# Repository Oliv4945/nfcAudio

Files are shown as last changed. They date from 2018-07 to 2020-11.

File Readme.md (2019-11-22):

# Project
nfcAudio is a wifi enabled MP3 player with NFC capability. A tag is placed on top and corresponding file is played.

# Software
Each time an RFID tag is detected:  
1. It is compared to volume tags
2. If a music is playing with the same tag, stop playing
3. Else GET an URL from embedded NDEF record
4. If there the file contains an URL to an MP3 file, play it.

## Libraries
This project depends on
* [ESP8266 Audio](https://github.com/earlephilhower/ESP8266Audio) - Wonderfull MP3 decoder
* [Adafruit PN532](https://github.com/Oliv4945/Adafruit-PN532/tree/interrupt_spi) - NFC library from Adafruit, which I modified to use interrupts instead of defalut blocking functions. `interrupt_spi` branch from my repo has to be used until my pull request is merged. (configured by default in `platformio.ini` file)

# Hardware
## Tags
Small stickers as well as standard "credit card" size tags can be used. I use a printed picture with thermal laminated film, but you can buy tags that can be printed if you have corresponding printer.  
Stickers can also be put underneath objects, toys, 3D printed things... Lot of fun for my 3 years old kid !

## Components
* I2S DAC MAX98357A - From [Adafruit](https://www.adafruit.com/product/3006)
* ESP8266 - [Wemos mini D1](https://wiki.wemos.cc/products:d1:d1_mini)
* NFC Reader PN532

## Wiring
### I2S DAC - MAX98357A
| I2S DAC board  | Wemos mini D1 mini pin  | ESP8266 pin  |
| --- |:---:| ----:|
| LRC | D4  | IO2  |
| BLCK | D8  | IO15 |
| DIN | RX  | IO3  |
| GND | GND | GND  |
| VCC | 5V  | |

### NFC Reader - PN532
| NFC Reader  | Wemos mini D1 mini pin  | ESP8266 pin  |
| --- |:---:| ----:|
| SCK | D5  | IO14 |
| MISO | D6  | IO12 |
| MOSI | D7  | IO13 |
| SS | D1  | IO5  |
| VCC | 3.3V| |
| GND | GND | GND  |
| IRQ | D2  | IO4  |
| RST | NC  | NC |

## Case
Design files are available in [onShape](https://cad.onshape.com/documents/462111829eacaa66e3425406/w/186305e0bc17a139465da4be/e/d87f807332cb58a96165f9d4), or in the [case](https://github.com/Oliv4945/nfcAudio/case) folder.  
The onShape model is fully parametrized, so all variables can be changed to fit you needs.

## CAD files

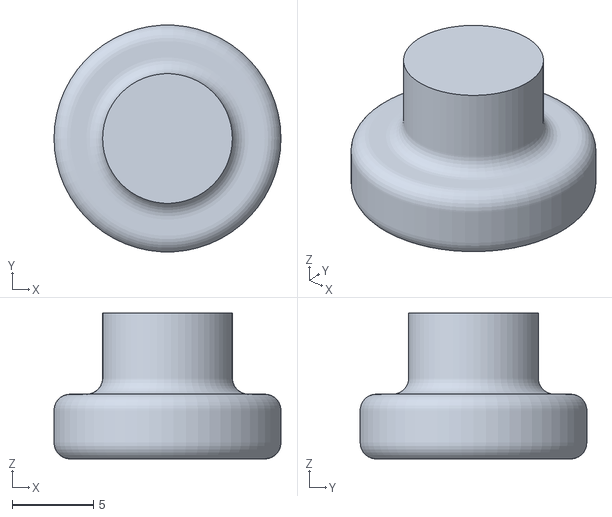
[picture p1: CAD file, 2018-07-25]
case/Foot.stl
14.0 x 14.0 x 9.00

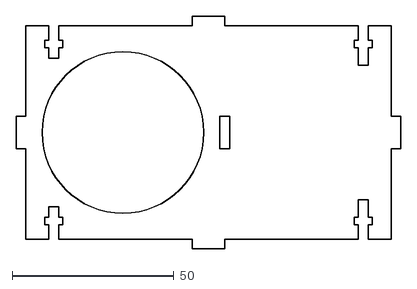
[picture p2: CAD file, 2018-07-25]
case/Bottom.dxf
119.0 x 72.0

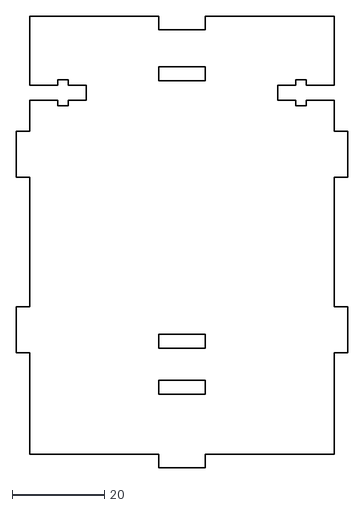
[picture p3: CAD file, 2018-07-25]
case/SideMiddle.dxf
72.0 x 98.0

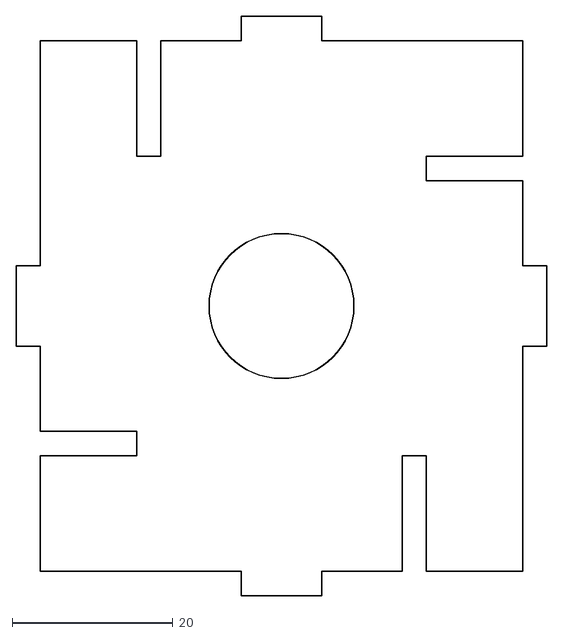
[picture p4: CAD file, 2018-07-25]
case/hpHolder.dxf
66.0 x 72.0

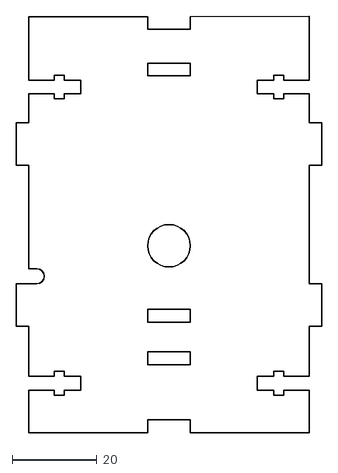
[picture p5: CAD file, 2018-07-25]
case/SideLeft.dxf
72.0 x 98.0

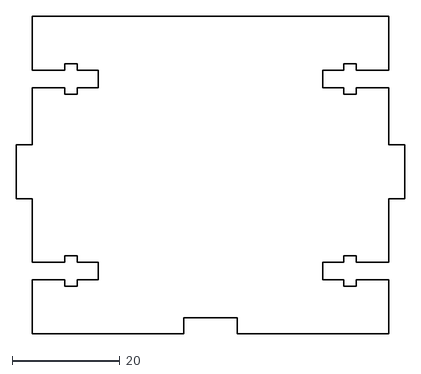
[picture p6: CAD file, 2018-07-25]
case/SideRight.dxf
72.0 x 58.8

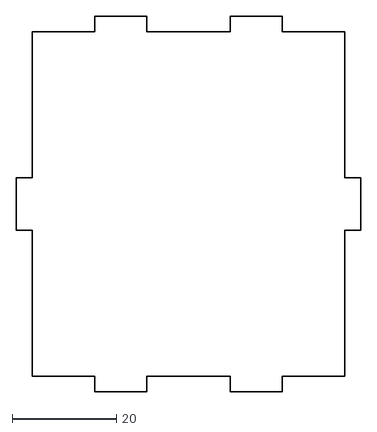
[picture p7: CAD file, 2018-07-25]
case/Top.dxf
66.0 x 72.0

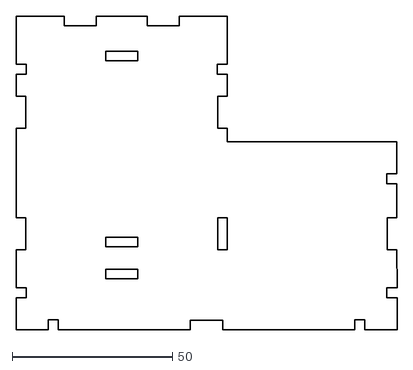
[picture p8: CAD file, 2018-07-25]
case/FrontBack_x2.dxf
119.0 x 98.0

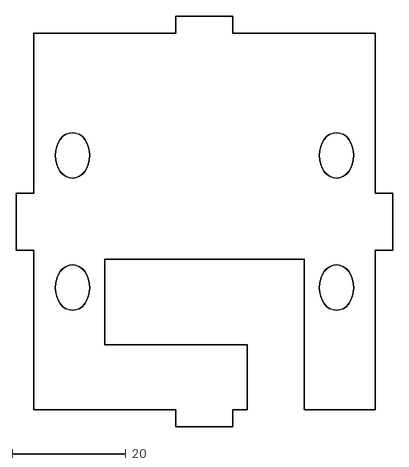
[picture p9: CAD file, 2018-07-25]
case/nfcHolder.dxf
66.0 x 72.0

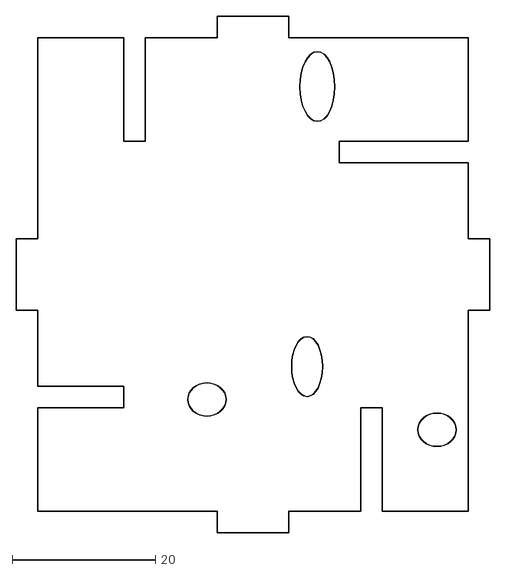
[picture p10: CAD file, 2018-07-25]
case/WemosAdcHolder.dxf
66.0 x 72.0

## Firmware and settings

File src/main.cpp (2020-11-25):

#include <Arduino.h>
#include <ESP8266WiFi.h>

#include <Wire.h>
#include <SPI.h>
#include "Adafruit_PN532.h"

#include "nfcPlayer.hpp"

#include "secrets.h"

// If using the breakout with SPI, define the pins for SPI communication.
#define PN532_SCK  (14)
#define PN532_MISO (12)
#define PN532_MOSI (13)
#define PN532_SS   (5)

// If using the breakout or shield with I2C, define just the pins connected
// to the IRQ and reset lines.  Use the values below (2, 3) for the shield!
#define PN532_IRQ   (4)
#define PN532_RESET (3)  // Not connected by default on the NFC Shield

// Hardware SPI
Adafruit_PN532 nfc(PN532_SS);


uint8_t uid[] = { 0, 0, 0, 0, 0, 0, 0 };  // Buffer to store the returned UID
uint8_t uidPlaying[]    = { 0, 0, 0, 0, 0, 0, 0 };  // Buffer to store the playing UID
uint8_t uidLength;                        // Length of the UID (4 or 7 bytes depending on ISO14443A card type)
uint8_t success = 0;
uint32_t timeoutNfc = 0;
bool interruptTriggered = false;
bool readerDisabled = false;


// Objects
nfcPlayer player;


// NFC interrupt handler
void ICACHE_RAM_ATTR handleInterrupt() {
  detachInterrupt(PN532_IRQ);
  interruptTriggered = true;
  readerDisabled = true;
}


void setup() {
  Serial.begin(115200);
  
  Serial.println("Connecting to WiFi");
  WiFi.begin(ssid, password);
  while (WiFi.status() != WL_CONNECTED) {
    delay(500);
    Serial.print(".");
  }
  Serial.println("\nIP address: ");
  Serial.println(WiFi.localIP());

  // NFC
  nfc.begin();
  uint32_t versiondata = nfc.getFirmwareVersion();
  if (! versiondata) {
    Serial.print("Didn't find PN53x board");
    while (1); // halt
  }
  // Got ok data, print it out!
  Serial.print("Found chip PN5"); Serial.println((versiondata>>24) & 0xFF, HEX); 
  Serial.print("Firmware ver. "); Serial.print((versiondata>>16) & 0xFF, DEC); 
  Serial.print('.'); Serial.println((versiondata>>8) & 0xFF, DEC);
  // configure board to read RFID tags
  nfc.SAMConfig();
  Serial.println("Waiting for an ISO14443A Card ...");

  // Register IRQ
  pinMode(PN532_IRQ, INPUT_PULLUP);
  nfc.startPassiveTargetIDDetection(PN532_MIFARE_ISO14443A);
  delay(500);
  attachInterrupt(digitalPinToInterrupt(PN532_IRQ), handleInterrupt, FALLING);
}


void processUid(uint8_t* uid, uint8_t uidLength) {
  String mp3Url;

  Serial.println("processUid");
  // Process volume
  if (memcmp(uid, uidVolumeDown, uidVolumeLen) == 0) {
    player.volumeDown();
    return;
  }
  if (memcmp(uid, uidVolumeUp, uidVolumeLen) == 0) {
    player.volumeUp();
    return;
  }
  // Stop playing in all cases
  if (player.isRunning()) player.stop();

  // Stop card
  if (memcmp(uid, uidStop, uidVolumeLen) == 0) {
    return;
  }

  // Try to read NTAG2xx memory and extract an URL
  // TODO: mifare classic/ultralight
  // TODO: Parsing from the app "NFC Reader" on Android Play store, not only the spec. To be validated
  // Read only the first record
  
  if (uidLength == 7) {

    uint8_t headerPage[4];
    // Read tag type, if any
    nfc.ntag2xx_ReadPage(4, headerPage);
    Serial.print("Header 4: ");
    nfc.PrintHex(headerPage, 4);
    Serial.println();
    if (headerPage[1] == 0x03) {
      Serial.println("NDEF RECORD");
      // Read header
      nfc.ntag2xx_ReadPage(5, headerPage);
      Serial.print("Header 5: ");
      nfc.PrintHex(headerPage, 4);
      Serial.println();
      if ((headerPage[3] && 0x07) == 0x01) {
        nfc.ntag2xx_ReadPage(6, headerPage);
        Serial.print("Header 6: ");
        nfc.PrintHex(headerPage, 4);
        Serial.println();
        Serial.println("NDEF - Well know record");
        if (headerPage[2] == 0x55) {
          Serial.println("NDEF - Well know URI");
          switch(headerPage[3]) {
            case 0x01:
              mp3Url = "http://www.";
              break;
            case 0x02:
              mp3Url = "https://www.";
              break;
            case 0x03:
              mp3Url = "http://";
              break;
            case 0x04:
              mp3Url = "https://";
              break;
            default:
              Serial.print("NDEF - Value: '0x");
              Serial.print(headerPage[3], HEX);
              Serial.println("' unknown.");
          }
          // Read URL
          uint8_t data[((headerPage[1]-1)/4+1)*4+1];
          for (uint8_t page = 7; page < ((headerPage[1]-1)/4+1) + 7; page ++) {
            nfc.ntag2xx_ReadPage(page, data + (page - 7) * 4);
          }
          data[headerPage[1]-1] = '\0';
          nfc.PrintHex(data, 12);
          mp3Url += String((char *) data);
          Serial.print("NDEF - URL: ");
          Serial.println(mp3Url);
        }
      }
    }
  }

  if (mp3Url.length() == 0) {
    // Try to connect to the server in order to get an URL to play
    WiFiClient client;
    if (!client.connect(host, port)) {
      Serial.println("connection failed");
      return;
    }
    String url = String("/nfcAudio/uid/0x");
    for (uint8_t i = 0; i< uidLength; i++) {
      url += String(uid[i], HEX);
    }
    Serial.print("URL: ");
    Serial.println(url);
    // Send request
    client.print(String("GET ") + url + " HTTP/1.1\r\n" +
                "Host: " + host + "\r\n" +
                "Connection: close\r\n\r\n"
      );
    unsigned long timeout = millis();
    while (client.available() == 0) {
      if (millis() - timeout > 5000) {
        Serial.println(">>> Client Timeout !");
        client.stop();
        return;
      }
    }
    // Read all the lines of the reply from server and print them to Serial
    uint8_t lineNumber = 1;
    while (client.available()) {
      String line = client.readStringUntil('\r');
      lineNumber++;
      /*
      Serial.print(lineNumber);
      Serial.print(" - ");
      Serial.println(line);
      */
      if (lineNumber==10) {
        Serial.print("Reading: ");
        // Remove CR then LF
        mp3Url = line.substring(1,line.length()-1); // TODO - Might be better to move it for each line
      }
    }
  }

  if (mp3Url.length() > 0) {
    Serial.printf("Playing: %s\n", mp3Url.c_str());
    player.readAudio(mp3Url);
    memcpy(uidPlaying, uid, uidLength);
    timeoutNfc = millis();
  }
}


void loop() {    
  // Wait for an ISO14443A type cards (Mifare, etc.).  When one is found
  // 'uid' will be populated with the UID, and uidLength will indicate
  // if the uid is 4 bytes (Mifare Classic) or 7 bytes (Mifare Ultralight)

  if (interruptTriggered == true) {
    success = nfc.readDetectedPassiveTargetID(uid, &uidLength);
    interruptTriggered = false;
  }
  
  if (success) {
    // Display some basic information about the card
    Serial.println("Found an ISO14443A card");
    Serial.print("  UID Length: ");
    Serial.print(uidLength, DEC);Serial.println(" bytes");
    Serial.print("  UID Value: ");
    nfc.PrintHex(uid, uidLength);
    Serial.println("");
    
    if (uidLength == 4) {
      // We probably have a Mifare Classic card ... 
      processUid(uid, 4);
    }
    
    if (uidLength == 7) {
      // We probably have a Mifare Ultralight card or NTAG ...
      processUid(uid, 7);
    }

    // Rearm for next tag, 
    success = 0;
    
  }

  if (readerDisabled == true) {
    // Reactivate reader after timeout
    if (abs(millis() - timeoutNfc) > timeoutAfterPlay) {
      readerDisabled = false;
      nfc.startPassiveTargetIDDetection(PN532_MIFARE_ISO14443A);
      attachInterrupt(digitalPinToInterrupt(PN532_IRQ), handleInterrupt, FALLING);
    }
  }

  // Audio stuff
  static int lastms = 0;

  if (player.isRunning()) {
    if (millis()-lastms > 1000) {
      lastms = millis();
      Serial.printf("Running for %d ms...\n", lastms);
      Serial.flush();
     }
    if (!player.loop()) player.stop();
  } else {
    Serial.printf("MP3 done\n");
    delay(1000);
  }
}

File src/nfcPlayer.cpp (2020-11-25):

#include "nfcPlayer.hpp"
#include <stdio.h>
#include "Arduino.h" // Dependancy for "Serial" object

#ifdef NFC_PLAYER_DEBUG_ON
  #define DEBUG(input) { Serial.print(input); }
  #define DEBUGln(input) { Serial.println(input); }
#else
  #define DEBUG(input);
  #define DEBUGln(input);
#endif


// Constructor
nfcPlayer::nfcPlayer() {
  // Init audio
  mp3 = new AudioGeneratorMP3();
  volume = 15;
};


// Called when a metadata event occurs (i.e. an ID3 tag, an ICY block, etc.
void nfcPlayer::callbackMetadata(void *cbData, const char *type, bool isUnicode, const char *string) {
  const char *ptr = reinterpret_cast<const char *>(cbData);
  (void) isUnicode; // Punt this ball for now
  // Note that the type and string may be in PROGMEM, so copy them to RAM for printf
  char s1[32], s2[64];
  strncpy_P(s1, type, sizeof(s1));
  s1[sizeof(s1)-1]=0;
  strncpy_P(s2, string, sizeof(s2));
  s2[sizeof(s2)-1]=0;
  // TODO: Serial.printf("METADATA(%s) '%s' = '%s'\n", ptr, s1, s2);
  DEBUG("METADATA("); DEBUG(ptr); DEBUG(") '"); DEBUG(s1); DEBUG("' = '"); DEBUG(s2); DEBUG("'\n");
}

// Called when there's a warning or error (like a buffer underflow or decode hiccup)
void nfcPlayer::callbackStatus(void *cbData, int code, const char *string) {
  const char *ptr = reinterpret_cast<const char *>(cbData);
  // Note that the string may be in PROGMEM, so copy it to RAM for printf
  char s1[64];
  strncpy_P(s1, string, sizeof(s1));
  s1[sizeof(s1)-1]=0;
  // TODO: Serial.printf("STATUS(%s) '%d' = '%s'\n", ptr, code, s1);
  DEBUG("STATUS("); DEBUG(ptr); DEBUG(") '"); DEBUG(code); DEBUG("' = '"); DEBUG(s1); DEBUG("'\n");
  // TODO: Serial.flush();
}


bool nfcPlayer::isRunning(void) {
  return mp3->isRunning();
}

bool nfcPlayer::loop(void) {
  return mp3->loop();
}

bool nfcPlayer::stop(void) {
  return mp3->stop();
}


void nfcPlayer::volumeDown(void) {
  volume -= 1;
  if (volume < 8) volume = 8;
  if (out) out->SetGain((float)volume / 100.0);
  DEBUG("Volume down: ");
  DEBUGln(volume);
}


void nfcPlayer::volumeUp(void) {
  volume += 1;
  if (volume > 90) volume = 90;
  if (out) out->SetGain((float)volume / 100.0);
  DEBUG("Volume up: ");
  DEBUGln(volume);
}



void nfcPlayer::stopPlaying() {
  if (mp3) {
    if (mp3->isRunning()) {
      mp3->stop();
      delete mp3;
      mp3 = NULL;
    }
  }
  if (out) {
    delete out;
    out = NULL;
  }
  if (buff) {
    buff->close();
    delete buff;
    buff = NULL;
  }
  if (file) {
    file->close();
    delete file;
    file = NULL;
  }
}


void nfcPlayer::readAudio(String mp3Url) {
  stopPlaying();
  out = new AudioOutputI2S();
  file = new AudioFileSourceHTTPStream(mp3Url.c_str());
  file->SetReconnect(3, 500);
  buff = new AudioFileSourceBuffer(file, 4096);
  out->SetGain((float)volume / 100.0);
  mp3->begin(buff, out);
}

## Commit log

2018-07-25 Add case files
    [Bottom.dxf, Foot.stl, FrontBack_x2.dxf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]
2018-07-29 Prevent running again the same audio file when stopping it
    [main.cpp]
2019-04-22 Bug correction when switching cards
    [main.cpp]
2019-11-22 Switch ICY to HTTP source, remove debug loosing time
